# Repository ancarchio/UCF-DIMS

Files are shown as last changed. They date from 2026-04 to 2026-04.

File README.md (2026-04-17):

## Linktree: https://linktr.ee/UCF_DIMS

## Contents:
- [DIMS.exe](DIMS.exe): WinForms App for installation/use, not editable
- [DIMS-Source](DIMS-Source)
  * [DIMS-Application.zip](DIMS-Source/DIMS-application.zip): Full, editable project files for winforms app
  * Arduino program (must be opened in a folder together)
    * [DIMS.h](DIMS-Source/DIMS.h): Header file with pin definitions and setup
    * [DIMS.ino](DIMS-Source/DIMS.ino): Main file with menu and helper functions
    * [InjectProcess.cpp](DIMS-Source/InjectProcess.cpp): Includes the injection process and data collection functions
- [DIMS-Assembly](DIMS-Assembly): Parts files for machine (all included files required to open assembly)
  * Full Assembly.SLDASM: Assembly File
  * Pieces.zip: Individual Parts
  * Mold Files.zip: Example Duck Mold and Customizable Mold Template

## To Use:
**READ THE FULL MANUAL BEFORE USE**
>[!NOTE]
>The DIMS Application is currently only available on Windows
1. Download the latest version of DIMS.exe and install
2. Turn on the machine
3. Plug the USB cord from the machine into the computer
4. Open the DIMS application
5. Under "Serial Connection", choose the COM port that the machine is attached to
6. Click connect
7. Data (temperatures, gate readings, relay states) should appear under "Current Data"
8. Input parameters under "Setup"
9. Ensure mold is properly placed and doors are closed
10. Click "Begin Injection" when ready
11. Once the process is complete and the mold is sufficiently cooled, remove from the machine

## Error Codes and Troubleshooting
### Type 1 Error: Invalid Entry
| Code  | Meaning |
|---|---|
| Er.11 | Invalid Desired Temperature, < 1 C or > 250 C |
| Er.12 | Invalid Heat Time, $\le$ 1 ms |
| Er.13 | Invalid Hold Time, $\le$ 1 ms |
| Er.14 | Invalid Cool Time, $\le$ 1 ms |

#### To Resolve:
* Check inputted parameters. Ensure all are above zero, and that the desired temperature is also below 250 C

### Type 2 Error: Attempting to Input Data Without Serial Connection
| Code  | Meaning |
|---|---|
| Er.20 | Not connected to serial |

>[!WARNING]
>Unplugging the machine from the computer without hitting "Disconnect" first will cause the application to crash instead of giving an error

#### To Resolve:
* Ensure machine is properly connected to your computer via the USB cable
* Ensure correct COM port is selected
  * If you cannot find the correct COM port, go to your Device Manager under COM Ports.\
    Unplug, then replugin the USB cable. Determine which COM appeared
  * If the COM still does not appear, refresh the application
  * If the machine does not appear in the Device Manager
    1. Restart Machine
    2. Turn off machine and check that the cord is plugged into the Arduino, unplug and replugin the cord
    3. The cord may be broken and require replacement
    4. If issues still persist, there is likely an issue with the Arduino itself

>[!NOTE]
>If a Type 3 or Type 4 Error occurs during an injection cycle, the heaters will be turned off and the solenoids will be deactivated\
>An error message will persist on the screen until the issue is resolved\
>Once the issue is resolved, the screen will return to the menu, and the cycle will not continue.\
>A purge cycle may need to be run before running another injection cycle.

### Type 3 Error: Overheating
| Code  | Meaning |
|---|--- |
| Er.31 | Barrel Overheating* (>300 C) |
| Er.32 | Electronics Overheating (>100 C) |
| Er.33 | Invalid Hold Time (>150 C) |

*"Barrel Overheating" counts if at least one barrel thermocouple is reading over 300 C, not just the average

>[!WARNING]
>**DO NOT OPEN THE MACHINE WHILE IT IS OVERHEATING!** Do not risk burning yourself or exposing yourself to fumes!\
>If you receive this error, immediately stop the injection process. You may leave the machine on, so the fans run.\
>Do not continue the injection process until the temperatures are back within safe values

#### To Resolve:
* Wait and allow the machine to cool down, following all safety protocols
  * If the overheat was genuine, ensure all functions are working properly. Inspect circuits for problems. Test machine before using again.
* If the temperature displayed is much higher than could be possible (ex. >1000 C), is switching between NaN, 0, and extremely high values,\
  Or, is much higher than the other temperatures (eg. BT1 is showing 30 C while BT2 is showing 350) There is likely an issue with at least one thermocouple.
  1. Make note of which thermocouple is reading incorrectly
  2. Disconnect the machine from the computer, turn off the machine, then unplug the machine
  3. Wait for the machine to cool down, especially if a cycle was run recently (wait at least 30 mins after the last cycle)
  4. Verify the thermocouple is not grounded (ie. not touching any metal parts that may be connected to the circuit)
     * All thermocouples have high-temp electric tape on/under them to prevent this. The tape may need to be replaced.
     * <ins>**Be extremely cautious when opening the insulation on the barrel to perform maintenance**</ins>
  5. Verify the connections of the thermocouple to the amplifiers and the amplifiers to the Arduino are secure
     * Tighten the screws on the amplifiers
     * Connections between the amplifiers and Arduino may need to be redone or reinforced
  6. If the issue persists, the thermocouple and/or amplifier may require replacement.

### Type 4 Error: Door Open (Gate sensor reading 1)
| Code  | Meaning |
|---|---|
| Er.31 | Gate 1 Open |
| Er.42 | Gate 2 Open |

>[!WARNING]
>NEVER OPEN THE MACHINE DURING PROCESSING!\
>There is a great injury risk due to the heat and pressure within the system.\
>If the process needs to be stopped at any time, use the E-Stop, then wait for the machine to cool down before opening it up

#### To Resolve:
* Close doors immediately
* If the error occurred while all the doors are closed, there may be an issue with the magnetic reed sensors:
  1. Make a note of which sensor failed (can be checked without running a cycle, under the Current Data section)
  2. Wait for the machine to cool down, turn it off, and unplug it
  3. Ensure the magnetic reed sensor and the associated magnet are in their correct positions
  4. Verify the connections of the sensor to the Arduino are secure
  5. If issues persist, the sensor may require replacement

>[!NOTE]
>All connections and input/output indexes can be found in the [README](DIMS-Source/README.md) under DIMS-Source

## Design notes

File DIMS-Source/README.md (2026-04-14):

# Using This Folder
## DIMS-Application.zip
This folder contains the project files for the DIMS WinForms App. This will allow you to edit the application. Download and extract the zip and open the solution in your IDE of choice (Visual Studio is recommended, as it was used to create the original application)

## Arduino Program
1. DIMS.ino
2. DIMS.h
3. InjectProcess.cpp

Download all 3 program files and open in the Arduino IDE.

The following libraries are needed:
* Arduino and Wire (both included with Arduino IDE)
* [Keypad](https://playground.arduino.cc/Code/Keypad/) by Mark Stanley and Alexander Brevig
* [Adafruit SSD1306](https://github.com/adafruit/Adafruit_SSD1306) by Adafruit
* [MAX6675 Library](https://github.com/adafruit/MAX6675-library) by Adafruit

### Program Flowchart


# Pin Connections

### Thermocouples
| BT1: | |
|---|---|
| GND  | Ground |
| VDD  | 5V |
| SCK  | 36 |
| CS | 34 |
| DO | 37 |

| BT2: | |
|---|---|
| GND  | Ground |
| VDD  | 5V |
| SCK  | 36 |
| CS | 29 |
| DO | 37 |

| ET: | |
|-----|---|
| GND | Ground |
| VDD | 5V |
| SCK | 39 |
| CS  | 42 |
| DO  | 38 |

| ET: | |
|-----|---|
| GND | Ground |
| VDD | 5V |
| SCK | 39 |
| CS  | 43 |
| DO  | 38 |

### Magnetic Reed Sensors

| G1: | |
|---|---|
| Brown | Ground |
| Blue  | 24 |

| G2: | |
|---|---|
| Brown  | Ground |
| Orange | 25 |

### Relays

| Double Relay | |
|---|---|
| DC- | Ground |
| DC+ | 5V |
| IN1 | 32 (sol) |
| IN2 | 33 (fan) |
| NO1 | Sol + |
| COM1 | Power +  |
| NC1 | Nothing  |
| NO2 | ACDC,AC+ |
| COM2 | Power, + |
| NC2 | Nothing  |

**Fans**
* Relay connects to AC+ on AC to DC converter
* Ground on AC cord connects to AC- on AC to DC converter
* Farthest pin on fans (inidicated by arrow), connects to DC- on AC to DC converter
* Next pin on fans connects to DC+ on AC to DC converter

**Solenoids**
* Relay connects to one side of the solenoids (red wire)
* Other wire (black) on solenoids connects to AC cord

| IOT Relay | |
|---|---|
| Black (-) | Ground  |
| White (+) | 28 |
| Norm. Off | Heaters |

### Interface 

| OLED: | |
|---|---|
| GND | Ground |
| VDD | 5V |
| SDA | 20 |
| SCL | 21 |

**Keypad:**
46-53, From * -> D in order

# Input/Output Indexes

The communication between the Arduino and the WinForms App is done using Serial communication with the following format:
>Index.Value

The index is always two characters, and the value can any integer or float\
Error codes follow the same format, and can be found in detail on the main README, but a summarized version can be found below.
## Input Indexes (sending to Arduino, must be in computer entry mode to work)

#### NT.____: "Nozzle Temperature"
- Sets desired temperature, accepts float

#### HT.____: "Heat Time"
- Sets heat time, accepts float. Value will be in minutes

#### WT.____: "Wait Time"
- Sets hold time, accepts float. Value will be in seconds

#### CT.____: "Cool Time"
- Sets cool time, accepts float. Value will be in minutes

#### PT.1: "Process Start"
- Begins injection process. Only accepts value = 1
- Sets processStart = 1

#### H1.____: "Heaters"
- value = 1: Turns on heaters
- value = 0: Turns off heaters

#### S1.____: "Solenoids"
- value = 1: Turns on solenoids (injects)
- value = 0: Turns off solenoids (raises)

#### F1.____: "Fans"
- value = 1: Turns on fans
- value = 2: Turns off fans

## Output Indexes (Sending data to WinForms App)

#### T1.____: "Barrel Temperature 1" (BT1)
#### T2.____: "Barrel Temperature 2" (BT2)
#### T3.____: "Electronics Temperature" (ET)
#### T4.____: "Mold Cavity Temperature" (MT)

#### G1.____: "Gate Sensor 1"
- value = 1: Gate sensor open (door open)
- value = 2: Gate sensor closed (door closed)

#### G2.____: "Gate Sensor 2"
- value = 1: Gate sensor open (door open)
- value = 2: Gate sensor closed (door closed)

#### IP.____: "Injection Process"
- Indicates current stage of injection process
- value = 1: Heating
- value = 2: Injecting then holding
- value = 3: Cooling
- value = 4: Complete

#### PT.____: "Process Time"
- Sets progress bar value = $\frac{Current Time - Start Time}{Cycle Step Time}$

#### HH.____: "Heaters"
- value = 1: Heaters are on
- value = 0: Heaters are off

#### SS.____: "Solenoids"
- value = 1: Solenoids are on (injected)
- value = 0: Solenoids are off (raised)

#### FF.____: "Fans"
- value = 1: Fans are on
- value = 2: Fans are off

## Error Codes (summary, see main README for more info on troubleshooting

### Type 1 Error: Invalid Entry
| Code  | Meaning |
|---|---|
| Er.11 | Invalid Desired Temperature, < 1 C or > 250 C |
| Er.12 | Invalid Heat Time, $\le$ 1 ms |
| Er.13 | Invalid Hold Time, $\le$ 1 ms |
| Er.14 | Invalid Cool Time, $\le$ 1 ms |

### Type 2 Error: Attempting to Input Data Without Serial Connection
| Code  | Meaning |
|---|---|
| Er.20 | Not connected to serial |

### Type 3 Error: Overheating
| Code  | Meaning |
|---|--- |
| Er.31 | Barrel Overheating* (>300 C) |
| Er.32 | Electronics Overheating (>100 C) |
| Er.33 | Invalid Hold Time (>150 C) |

### Type 4 Error: Door Open (Gate sensor reading 1)
| Code  | Meaning |
|---|---|
| Er.31 | Gate 1 Open |
| Er.42 | Gate 2 Open |

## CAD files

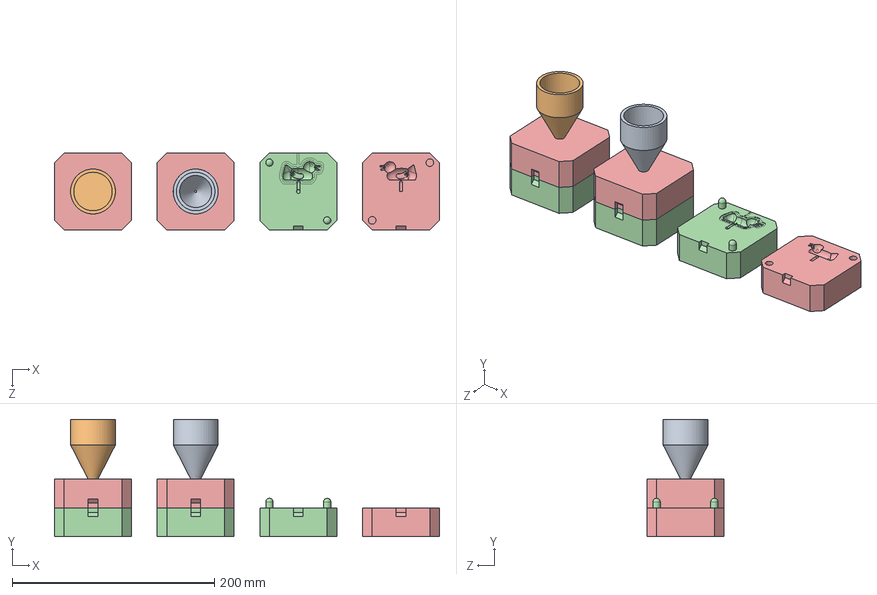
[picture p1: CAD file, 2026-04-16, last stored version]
DIMS-Assembly/Mold Files/Mold Design iteration 8.SLDASM
381.0 x 116.2 x 76.2 mm
Top block iteration 8 x 3
Bottom block iteration 8 x 3
Bigger Duck Mold
nozzle (filled in)
nozzle (open)

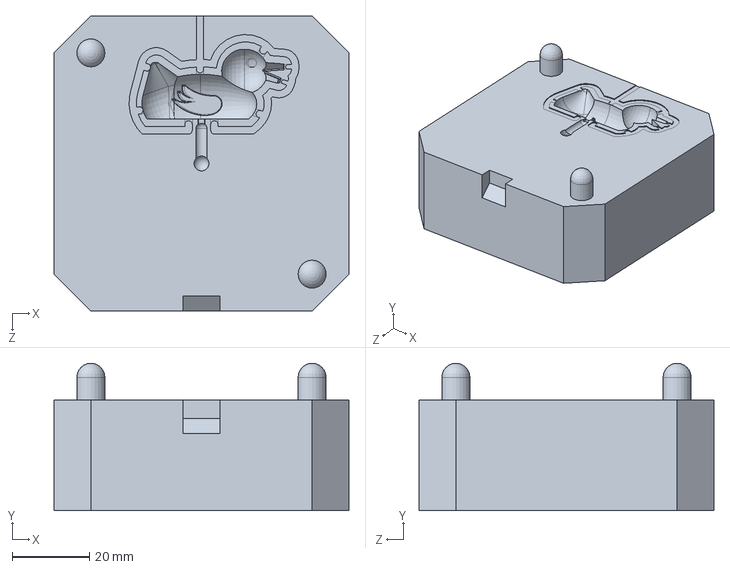
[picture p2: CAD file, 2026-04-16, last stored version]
DIMS-Assembly/Mold Files/Bottom block iteration 8.SLDPRT
76.2 x 38.1 x 76.2 mm

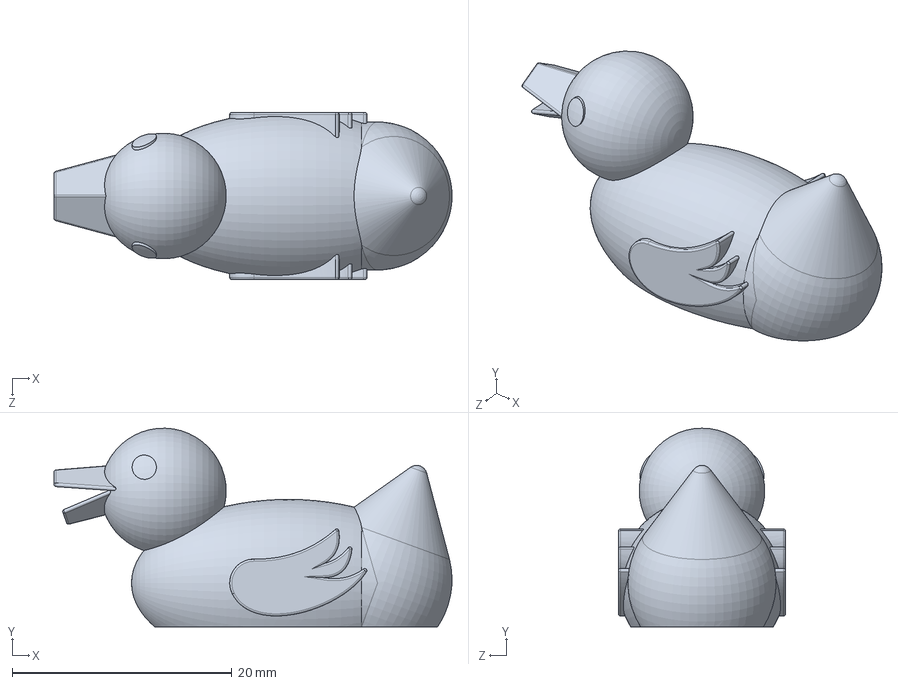
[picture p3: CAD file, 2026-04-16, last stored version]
DIMS-Assembly/Mold Files/Bigger Duck Mold.SLDPRT
36.2 x 18.1 x 15.2 mm

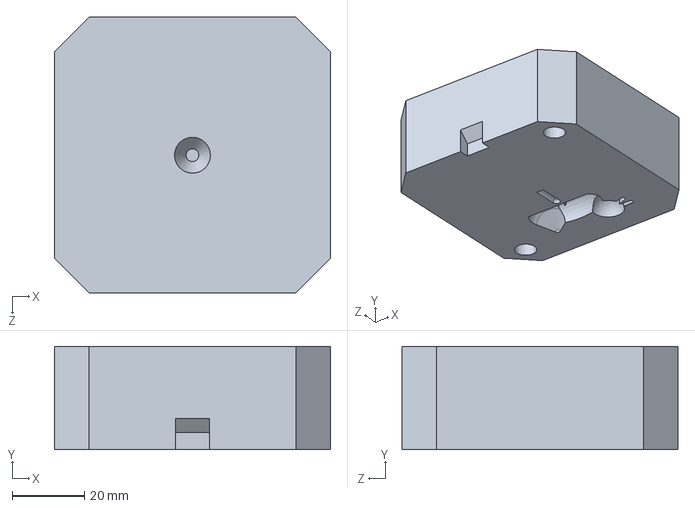
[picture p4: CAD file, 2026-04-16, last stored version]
DIMS-Assembly/Mold Files/Top block iteration 8.SLDPRT
76.2 x 28.6 x 76.2 mm

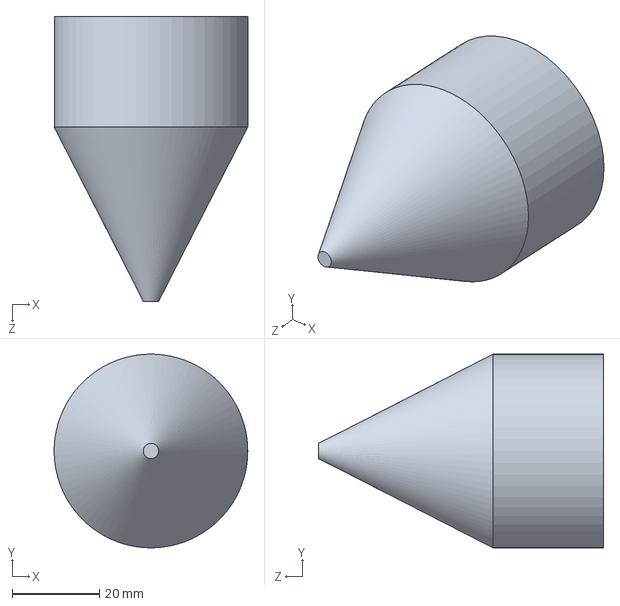
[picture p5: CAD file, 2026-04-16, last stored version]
DIMS-Assembly/Mold Files/nozzle (filled in).SLDPRT
44.4 x 44.4 x 65.4 mm

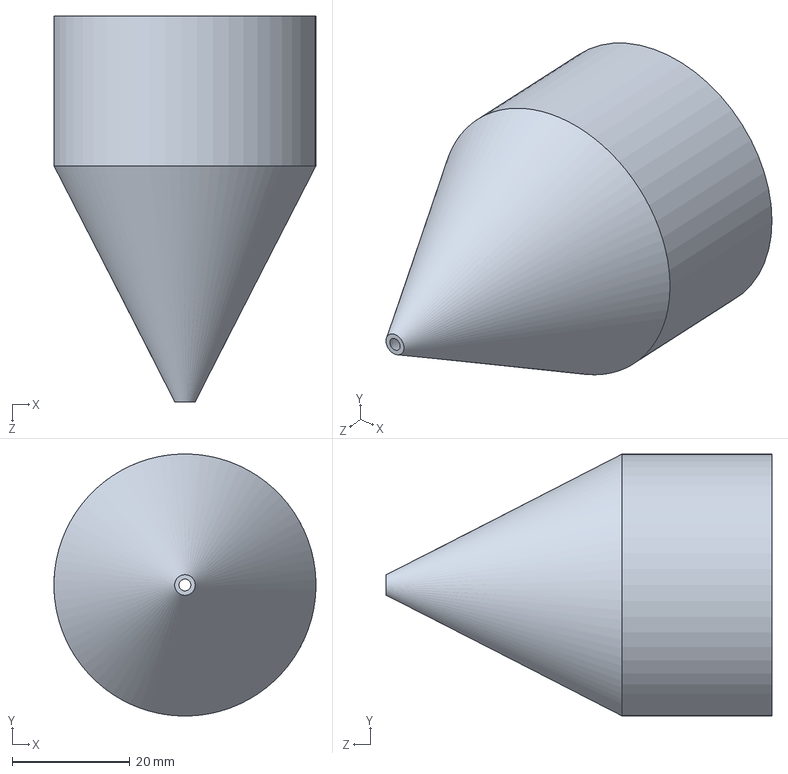
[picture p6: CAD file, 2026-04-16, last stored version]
DIMS-Assembly/Mold Files/nozzle (open).SLDPRT
44.4 x 44.4 x 65.4 mm

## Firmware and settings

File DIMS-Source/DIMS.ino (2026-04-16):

#include "DIMS.h"

//Global Object/Variable Defs

//Thermocouple Defs
MAX6675 thermocoupleBT1(CLK1, BT1CS, DO1);
MAX6675 thermocoupleBT2(CLK1, BT2CS, DO1);
MAX6675 thermocoupleET (CLK2, ETCS,  DO2);
MAX6675 thermocoupleMT (CLK2, MTCS,  DO2);

//Display Def
Adafruit_SSD1306 display(SCREEN_WIDTH, SCREEN_HEIGHT, &Wire, -1);

//Keypad Defs
char hexaKeys[ROWS][COLS] = {
  { '1', '2', '3', 'A' },
  { '4', '5', '6', 'B' },
  { '7', '8', '9', 'C' },
  { '.', '0', '#', 'D' }
};
byte rowPins[ROWS] = { 46, 47, 48, 49 };
byte colPins[COLS] = { 50, 51, 52, 53 };
Keypad customKeypad = Keypad(makeKeymap(hexaKeys), rowPins, colPins, ROWS, COLS);

char         key          = 0;
int          entryComplete = 0;
const byte   MAX_CHARS    = 10;
char         inputBuffer[10];
byte         inputIndex   = 0;
float        floatTotal   = 0;
unsigned int intTotal     = 0;

//Paramter Setup
float currTemp    = 0;
float desiredTemp = 0;

float startTime = 0;
float currTime  = 0;
float heatTime  = 0;
float holdTime  = 0;
float coolTime  = 0;

int processStart = 0;

void setup() {
  Serial.begin(115200);

  //Display Setup
  if (!display.begin(SSD1306_SWITCHCAPVCC, 0x3C)) {
    Serial.println(F("SSD1306 allocation failed"));
    for (;;);
  }
  delay(2000);
  display.clearDisplay();
  display.setTextSize(1);
  display.setTextColor(WHITE);
  display.setCursor(0, 0);
  display.println("Welcome!");
  display.display();
  delay(2000);

  //Heater, Fan, Solenoid, Reed Sensor Setup
  digitalWrite(SOL, RAISE);
  digitalWrite(FAN, HIGH); //Start with fan on by default
  digitalWrite(HEATER, LOW);

  pinMode(HEATER, OUTPUT);
  pinMode(FAN,    OUTPUT);
  pinMode(SOL,    OUTPUT);
  pinMode(G1, INPUT_PULLUP);
  pinMode(G2, INPUT_PULLUP);

  Serial.println("FF.1");
  Serial.println("SS.0");
  Serial.println("HH.0");
  displayMenu();
}

void loop() {
  key = customKeypad.getKey(); //Check is keypad has been pressed

  if (millis() % 500 == 0) { //Every 500 ms, get data
    getData();
  }

  if (key == 'A') {  // Use computer to input parameters
    display.clearDisplay();
    display.setCursor(0, 0);
    display.println("Enter data on computer");
    display.display();
    while (true) {
      if (millis() % 500 == 0) { //Every 500 ms, get data
        getData();
      }

      while (Serial.available()) { //Check for data sent from computer
        String input = Serial.readStringUntil('\n');
        String index = input.substring(0, 3);
        String value = input.substring(3);
        if (index == "NT.") { //Set desired temperature
          desiredTemp = value.toFloat();
        } else if (index == "HT.") { //Set heat time
          heatTime = value.toFloat() * 60000;
        } else if (index == "WT.") { //Set hold time
          holdTime = value.toFloat() * 1000;
        } else if (index == "CT.") { //Set cool time
          coolTime = value.toFloat() * 60000;
        } else if (index == "S1.") { //Turn on/off solenoid
          digitalWrite(SOL, value == "1" ? LOWER : RAISE);
        } else if (index == "H1.") { //Turn on/off heater
          digitalWrite(HEATER, value == "1" ? HIGH : LOW);
        } else if (index == "F1.") { //Turn on/off fan
          digitalWrite(FAN, value == "1" ? HIGH : LOW);
          Serial.print("FF.");
          Serial.println(value);
        } else if (input == "PS.1") { //Start process
          processStart = 1;
        }
      }

      if (processStart > 0) {
        if (desiredTemp <= 1 || desiredTemp > 250 || heatTime <= 1 || holdTime <= 1 || coolTime <= 1) {
          display.clearDisplay();
          display.setCursor(0, 0);
          display.println("Settings are invalid\nReturning to menu");
          display.display();
          if (desiredTemp <= 1 || desiredTemp > 250) Serial.println("Er.11");
          if (heatTime <= 1) Serial.println("Er.12");
          if (holdTime <= 1) Serial.println("Er.13");
          if (coolTime <= 1) Serial.println("Er.14");
          processStart = 0;
          delay(2000);
          displayMenu();
        } else {
          processStart = 1;
          injectionProcess();
          displayMenu();
          break;
        }
      }
    }
  }

  if (key == 'B') {  // Set temperature and heat time via keypad
    desiredTemp = getDesiredTemp();
    heatTime    = getHeatTime();
    delay(2000);
    displayMenu();
  }

  if (key == 'C') {  // Set hold/cool times via keypad
    holdTime = getHoldTime();
    coolTime = getCoolTime();
    delay(2000);
    displayMenu();
  }

  if (key == 'D') {  // Begin process
    if (desiredTemp <= 1 || heatTime <= 1 || holdTime <= 1 || coolTime <= 1) {
      Serial.print(desiredTemp); Serial.print(",");
      Serial.print(heatTime);   Serial.print(",");
      Serial.print(holdTime);   Serial.print(",");
      Serial.println(coolTime);
      display.clearDisplay();
      display.setCursor(0, 0);
      display.println("Settings are invalid\nReturning to menu");
      display.display();
      delay(2000);
      displayMenu();
    } else {
      processStart = 1;
      injectionProcess();
      displayMenu();
    }
  }
}

//Other helper functions

void displayMenu() {
  display.clearDisplay();
  display.setCursor(0, 0);
  display.println("A: Use Computer Data");
  display.println("B: Set Temperature");
  display.println("C: Set Timing");
  display.println("D: Begin Process");
  display.display();
}


void readKeypad() {
  key = customKeypad.getKey();

  if (key == '#') {
    floatTotal = atof(inputBuffer);
    Serial.println();
    Serial.println("entry is complete");
    display.clearDisplay();
    display.setCursor(0, 0);
    display.print("Value Entered: ");
    display.println(floatTotal, 2);
    display.display();
    entryComplete = checkValue();

    if (entryComplete < 1) {
      floatTotal = 0;
      inputIndex = 0;
      Serial.println("Re-enter Value");
      display.clearDisplay();
      display.setCursor(0, 0);
      display.println("Re-enter Value");
      display.display();
    }
    if (entryComplete > 0) {
      return;
    }
  }
  if ((key >= '0' && key <= '9') || key == '.') {
    inputBuffer[inputIndex] = key;
    if (inputIndex != MAX_CHARS - 1) {
      inputIndex++;
    }
    inputBuffer[inputIndex] = '\0';
    Serial.println(inputBuffer);
    display.println(inputBuffer);
    display.display();
  }
}

float getDesiredTemp() {
  Serial.println("Enter Desired Temperature: ");
  display.clearDisplay();
  display.setCursor(0, 0);
  display.println("Enter Desired Temp (C):");
  display.display();
  entryComplete = 0;
  while (entryComplete < 1) {
    readKeypad();
    if (entryComplete) {
      desiredTemp = floatTotal;
      Serial.print("Desired Temperature is ");
      Serial.print(desiredTemp, 2);
      Serial.println(" deg C");
      display.clearDisplay();
      display.setCursor(0, 0);
      display.print("Desired Temp: ");
      display.print(desiredTemp, 2);
      display.println("C");
      display.display();
      floatTotal = 0;
      inputIndex = 0;
    }
  }
  return desiredTemp;
}

float getHeatTime() {
  Serial.println("Enter Heat Time ");
  display.clearDisplay();
  display.setCursor(0, 0);
  display.println("Enter Heat Time (min):");
  display.display();
  entryComplete = 0;
  while (entryComplete < 1) {
    readKeypad();
    if (entryComplete) {
      heatTime = floatTotal;
      Serial.print("Heat Time is ");
      Serial.print(heatTime, 2);
      Serial.println("min");
      display.clearDisplay();
      display.setCursor(0, 0);
      display.print("Heat Time: ");
      display.print(heatTime, 2);
      display.println("min");
      display.display();
      heatTime   = heatTime * 60000;
      floatTotal = 0;
      inputIndex = 0;
    }
  }
  return heatTime;
}

int checkValue() {
  Serial.println("Is value shown correct?\n Press A if correct\n Press B if not");
  display.println("Is value shown right?");
  display.println("Press A if correct");
  display.println("Press B if incorrect");
  display.display();
  while (true) {
    key = customKeypad.getKey();
    if (key == 'A') {
      return 1;
    }
    if (key == 'B') {
      return 0;
    }
  }
}

float getHoldTime() {
  Serial.println("Enter Hold Time ");
  display.clearDisplay();
  display.setCursor(0, 0);
  display.println("Enter Hold Time (s):");
  display.display();
  entryComplete = 0;
  while (entryComplete < 1) {
    readKeypad();
    if (entryComplete) {
      holdTime = floatTotal;
      Serial.print("Hold Time is ");
      Serial.print(holdTime, 2);
      Serial.println("s");
      display.clearDisplay();
      display.setCursor(0, 0);
      display.print("Hold Time: ");
      display.print(holdTime, 2);
      display.println("s");
      display.display();
      holdTime   = holdTime * 1000;
      floatTotal = 0;
      inputIndex = 0;
    }
  }
  return holdTime;
}

float getCoolTime() {
  Serial.println("Enter Cool Time ");
  display.clearDisplay();
  display.setCursor(0, 0);
  display.println("Enter Cool Time (min):");
  display.display();
  entryComplete = 0;
  while (entryComplete < 1) {
    readKeypad();
    if (entryComplete) {
      coolTime = floatTotal;
      Serial.print("Cool Time is ");
      Serial.print(coolTime, 2);
      Serial.println("min");
      display.clearDisplay();
      display.setCursor(0, 0);
      display.print("Cool Time: ");
      display.print(coolTime, 2);
      display.println("min");
      display.display();
      coolTime   = coolTime * 60000;
      floatTotal = 0;
      inputIndex = 0;
    }
  }
  return coolTime;
}

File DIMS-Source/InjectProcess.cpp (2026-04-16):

#include "DIMS.h"
#include <Arduino.h>

//Function to run injection
void injectionProcess() {
  getData();
  digitalWrite(FAN, HIGH); //Fans are always on during processing
  Serial.println("FF.1");
  display.clearDisplay();
  display.setCursor(0, 0);
  display.print("Beginning process \n Heating Plastic to ");
  display.print(desiredTemp, 2);
  display.println("C");
  display.print("For");
  display.print(heatTime / 60000, 2);
  display.print("seconds");
  display.display();
  Serial.println("IP.1");
  startTime = millis();
  currTime = millis();
  while (startTime + heatTime > currTime && processStart == 1) {  //Heat so outer temp == input for heatTime seconds
    getData();
    currTemp = (thermocoupleBT1.readCelsius() + thermocoupleBT2.readCelsius()) / 2;
    if (currTemp < desiredTemp) {
      digitalWrite(HEATER, HIGH);
      Serial.println("HH.1");
    } else {
      digitalWrite(HEATER, LOW);
      Serial.println("HH.0");
    }
    display.clearDisplay();
    display.setCursor(0, 0);
    display.print("Desired Temp: ");
    display.print(desiredTemp, 2);
    display.println("C");
    display.print("Current Temp: ");
    display.println(currTemp, 2);
    display.print("Current Time: ");
    display.println((currTime - startTime) / 60000, 2);
    display.print("Of ");
    display.print(heatTime / 60000, 2);
    display.print("min");
    display.display();
    Serial.print("PT.");
    Serial.println(100 * (currTime - startTime) / heatTime);
    delay(250);
    currTime = millis();
  }
  getData();
  if (processStart == 0) return; //Do not continue if there was an error
  digitalWrite(HEATER, LOW);
  Serial.println("HH.0");
  Serial.println("IP.2");
  display.clearDisplay();
  display.setCursor(0, 0);
  display.print("Injecting");
  display.display();
  delay(1000);
  digitalWrite(SOL, LOWER);  //Activate pneumatics
  Serial.println("SS.1");
  startTime = millis();
  currTime = millis();
  while (startTime + holdTime > currTime && processStart == 1) {  //Hold with pressure
    getData();
    display.clearDisplay();
    display.setCursor(0, 0);
    display.print("Holding for ");
    display.print(holdTime / 1000, 2);
    display.println("s");
    display.print("Current Time: ");
    display.print((currTime - startTime) / 1000, 2);
    display.display();
    Serial.print("PT.");
    Serial.println(100 * (currTime - startTime) / holdTime);
    currTime = millis();
  }
  getData();
  if (processStart == 0) return; //Do not continue if there was an error
  digitalWrite(SOL, RAISE);  //Deactivate pneumatics
  Serial.println("IP.3");
  Serial.println("SS.0");
  startTime = millis();
  currTime = millis();
  while (startTime + coolTime > currTime && processStart == 1) {  //Cool without pressure
    getData();
    display.clearDisplay();
    display.setCursor(0, 0);
    display.print("Cooling for ");
    display.print(coolTime / 60000, 2);
    display.println("min");
    display.print("Current Time: ");
    display.print((currTime - startTime) / 60000, 2);
    display.display();
    Serial.print("PT.");
    Serial.println(100 * (currTime - startTime) / coolTime);
    currTime = millis();
  }
  Serial.println("IP.4");
  display.clearDisplay();
  display.setCursor(0, 0);
  display.println("Process complete\nCarefully remove mold");
  display.display();
  processStart = 0;
  delay(5000);
  displayMenu();
}

void getData() {

  //Check Temperatures
  float tempBarrel1 = thermocoupleBT1.readCelsius();
  float tempBarrel2 = thermocoupleBT2.readCelsius();
  float electronicsTemp = thermocoupleET.readCelsius();
  float moldTemp = thermocoupleMT.readCelsius();

  //Check reed sensors
  int gate1 = digitalRead(G1);
  int gate2 = digitalRead(G2);

  //Check for overheating
  if (electronicsTemp > 100 || moldTemp > 150 || tempBarrel1 > 300 || tempBarrel2 > 300) {
    digitalWrite(HEATER, LOW); //Turn off heaters
    digitalWrite(SOL,    RAISE); //Set solenoids to not injected
    display.clearDisplay();
    display.setCursor(0, 0);
    display.println("Overheating");
    display.println("Allow machine to cool down");
    display.display();
    //Send errors to computer
    if (tempBarrel1 > 300 || tempBarrel2 > 300) Serial.println("Er.31");
    if (electronicsTemp > 100)                  Serial.println("Er.32");
    if (moldTemp > 150)                         Serial.println("Er.33");
    delay(2000);
    processStart = 0; //Stop processing
    //Wait for temperatures to be back to normal
    while (electronicsTemp > 100 || moldTemp > 150 || tempBarrel1 > 300 || tempBarrel2 > 300) {
      tempBarrel1 = thermocoupleBT1.readCelsius();
      tempBarrel2 = thermocoupleBT2.readCelsius();
      electronicsTemp = thermocoupleET.readCelsius();
      moldTemp = thermocoupleMT.readCelsius();
      Serial.print("T1."); Serial.println(tempBarrel1, 2);
      Serial.print("T2."); Serial.println(tempBarrel2, 2);
      Serial.print("T3."); Serial.println(electronicsTemp, 2);
      Serial.print("T4."); Serial.println(moldTemp, 2);
      delay(2000);
    }
  }

  //Check for open door (during injection only)
  if ((gate1 != 0 || gate2 != 0) && processStart == 1) {
    digitalWrite(HEATER, LOW); //Turn off heaters
    digitalWrite(SOL,    RAISE); //Set solenoids to not injected
    display.clearDisplay();
    display.setCursor(0, 0);
    display.println("Do Not Open Door");
    display.println("During Processing");
    display.display();
    delay(2000);
    processStart = 0; //Stop processing
    //Send errors
    if (gate1 != 0) Serial.println("Er.41");
    if (gate2 != 0) Serial.println("Er.42");
    //Wait for door to close
    while (gate1 != 0 || gate2 != 0) {
      gate1 = digitalRead(G1);
      gate2 = digitalRead(G2);
      Serial.print("G1."); Serial.println(gate1);
      Serial.print("G2."); Serial.println(gate2);
      delay(500);
    }
  }

  //Send data to computer
  Serial.print("T1."); Serial.println(tempBarrel1, 2);
  Serial.print("T2."); Serial.println(tempBarrel2, 2);
  Serial.print("T3."); Serial.println(electronicsTemp, 2);
  Serial.print("T4."); Serial.println(moldTemp, 2);
  Serial.print("G1."); Serial.println(gate1);
  Serial.print("G2."); Serial.println(gate2);
}

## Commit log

2026-04-16 I messed up ;(, it'll all be ok though
    [Bigger Duck Mold.SLDPRT, Bottom block iteration 8.SLDPRT, Mold Design iteration 8.SLDASM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]
2026-04-17 Delete DIMS-Assembly/Mold Files.zip
    More files were added to new version of this file
2026-04-17 Update README.md
    Added that I added the Mold Files to the Assembly File
